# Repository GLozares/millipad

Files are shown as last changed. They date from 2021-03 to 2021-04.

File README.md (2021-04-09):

# MilliPad
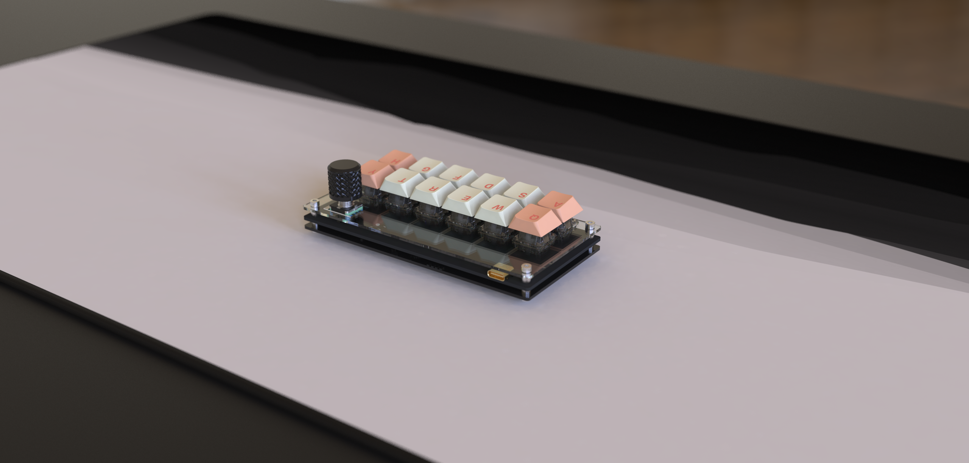
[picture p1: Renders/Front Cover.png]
Images


## A First Step into the World of Keyboards
Hi there! If you're reading this, thank you for stopping by. This is a repository detailing my first foray into custom mechanical keyboards. I decided to make a custom mechanical keypad to use for myself as my favorite keyboard layout, the 65%, does not have F1 through F12. However, in some circumstances particularly when I am coding, I would like to have those function keys. Thus, instead of buying a numpad off the shelf, I thought it was a great opportunity to make my own.

Prior to this project, I took on a group project in my Computer Engineering senior design class that involves creating our own full sized custom mechanical keyboard. I took some initiative and began to learn PCB design myself as to be a bigger asset to my group down the line.

## Credits
Apart from the dependant repositories already linked in my project, I would like to thank ai03 for their beginner's tutorial on keyboard PCB design. Their guide can be found at https://wiki.ai03.com/books/pcb-design.

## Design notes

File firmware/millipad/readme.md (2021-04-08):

# millipad

millipad

A 2x6 Macropad with Rotary Encoder. Designed to be cheap and usable.

* Keyboard Maintainer: [Jirou](https://github.com/GLozares)
* Hardware Supported: Jirou.Design Millipad
* Hardware Availability: Sag#0001

Make example for this keyboard (after setting up your build environment):

    make millipad:default

Flashing example for this keyboard:

    make millipad:default:flash

See the [build environment setup](https://docs.qmk.fm/#/getting_started_build_tools) and the [make instructions](https://docs.qmk.fm/#/getting_started_make_guide) for more information. Brand new to QMK? Start with our [Complete Newbs Guide](https://docs.qmk.fm/#/newbs).

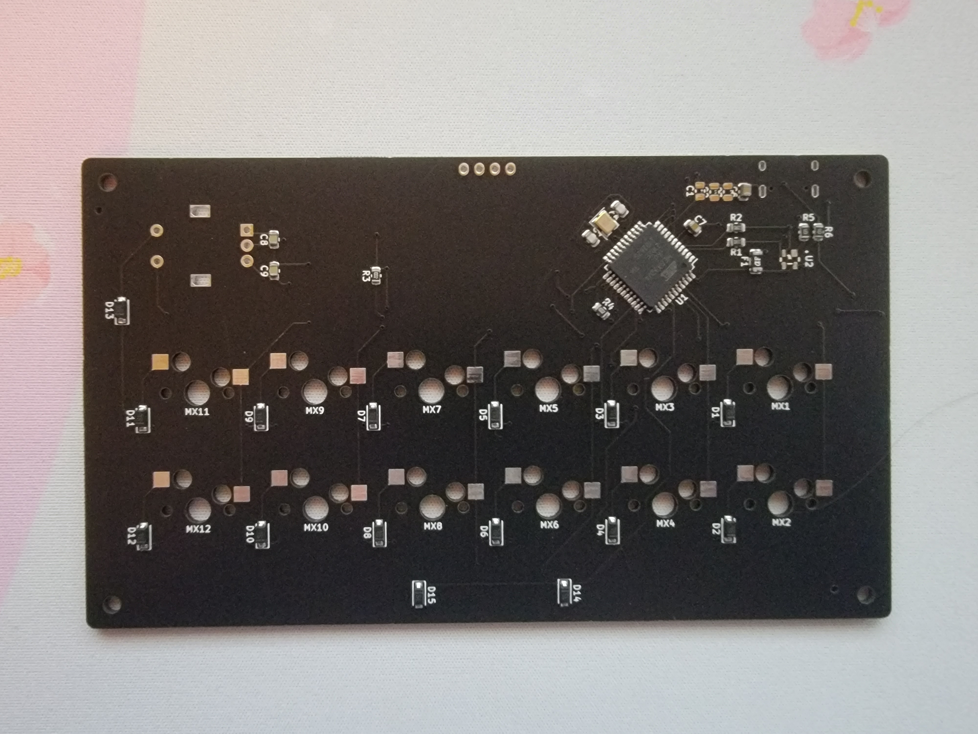
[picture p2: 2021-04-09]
miscellaneous-pictures/physical-pcb-back.jpg

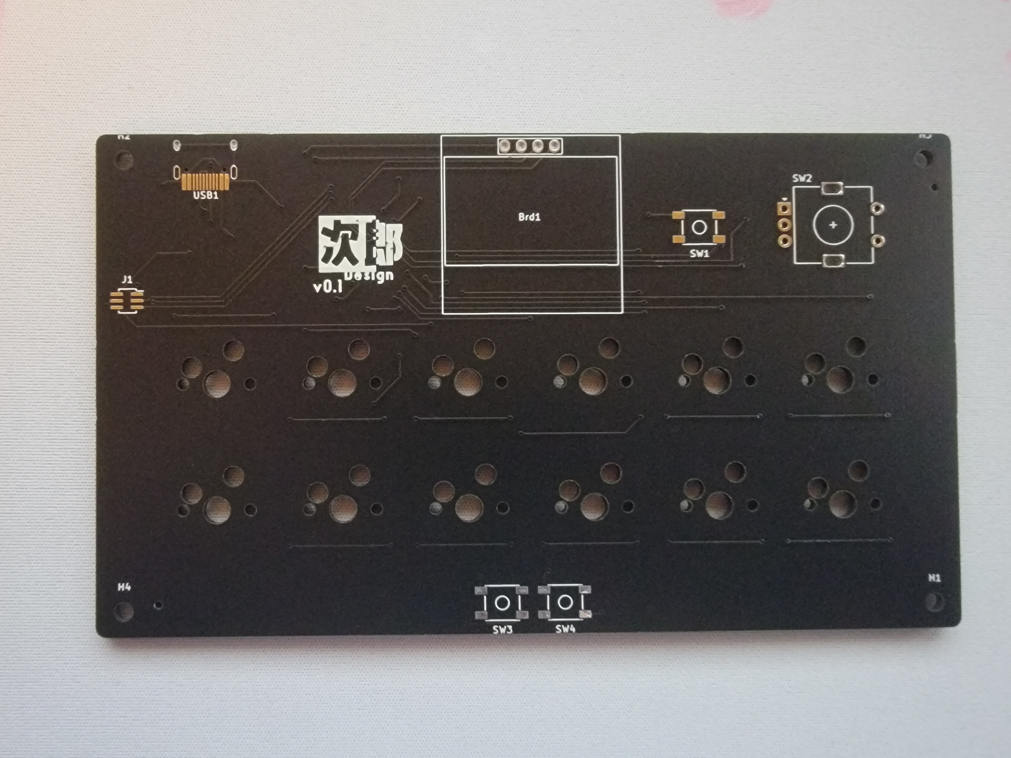
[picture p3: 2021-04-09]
miscellaneous-pictures/physical-pcb-front.jpg

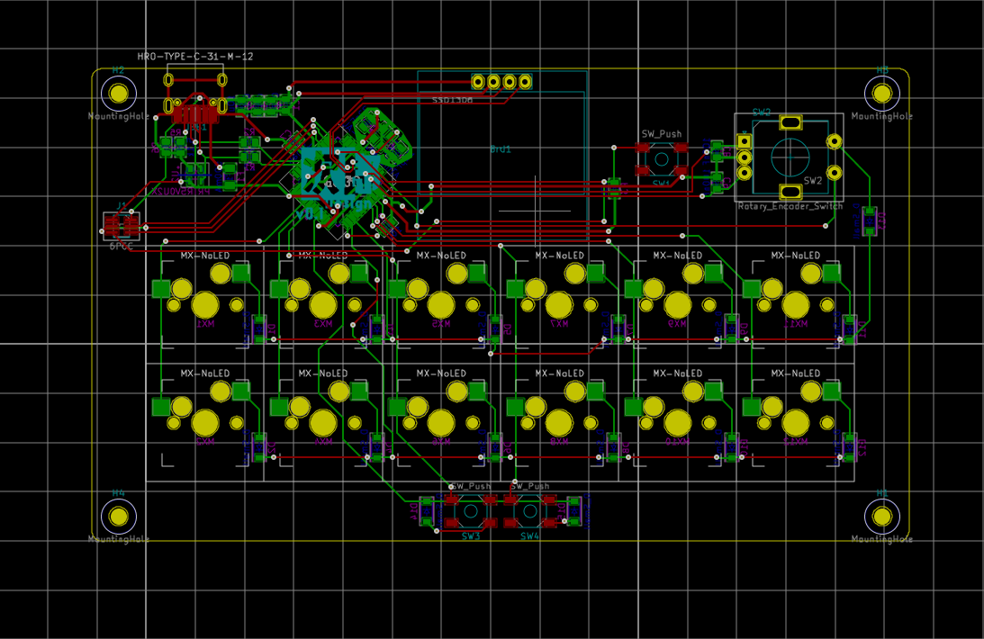
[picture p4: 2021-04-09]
miscellaneous-pictures/pcb-layout.png

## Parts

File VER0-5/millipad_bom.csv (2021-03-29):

Reference | Quantity | Value | Footprint | Datasheet
Brd1 | 1 | SSD1306 | SSD1306:128x64OLED
C1 C2 C3 | 3 | 0.1uF | Capacitor_SMD:C_0805_2012Metric | ~
C4 C5 | 2 | 22pF | Capacitor_SMD:C_0805_2012Metric | ~
C6 | 1 | 10uF | Capacitor_SMD:C_0805_2012Metric | ~
C7 | 1 | C_Small | Capacitor_SMD:C_0805_2012Metric | ~
C8 C9 | 2 | 100nF | Capacitor_SMD:C_0805_2012Metric | ~
D1 D2 D3 D4 D5 D6 D7 D8 D9 D10 D11 D12 D13 D14 D15 | 15 | D_Small | Diode_SMD:D_SOD-123 | ~
F1 | 1 | 500mA | Fuse:Fuse_1206_3216Metric | ~
H1 H2 H3 H4 | 4 | MountingHole | MountingHole:MountingHole_2.7mm_M2.5 | ~
J1 | 1 | 6P6C | Connector_PinSocket_1.00mm:PinSocket_2x03_P1.00mm_Vertical_SMD | ~
MX1 MX2 MX3 MX4 MX5 MX6 MX7 MX8 MX9 MX10 MX11 MX12 | 12 | MX-NoLED | MX_Only:MXOnly-1U-Hotswap
R1 R2 | 2 | 22 | Resistor_SMD:R_0805_2012Metric | ~
R3 R4 | 2 | 10k | Resistor_SMD:R_0805_2012Metric | ~
R5 R6 | 2 | 5.1k | Resistor_SMD:R_0805_2012Metric | ~
SW1 SW3 SW4 | 3 | SW_Push | random-keyboard-parts:SKQG-1155865 | ~
SW2 | 1 | Rotary_Encoder_Switch | Keebio-Parts:RotaryEncoder_Alps_EC11E-Switch_Vertical_H20mm | ~
U1 | 1 | ATmega32U4-AU | Package_QFP:TQFP-44_10x10mm_P0.8mm | http://ww1.microchip.com/downloads/en/DeviceDoc/Atmel-7766-8-bit-AVR-ATmega16U4-32U4_Datasheet.pdf
U2 | 1 | PRTR5V0U2X | prtr5v:PRTR5V0U2X
USB1 | 1 | HRO-TYPE-C-31-M-12 | Type-C:HRO-TYPE-C-31-M-12-HandSoldering
Y1 | 1 | 16MHz | Crystal:Crystal_SMD_3225-4Pin_3.2x2.5mm | ~

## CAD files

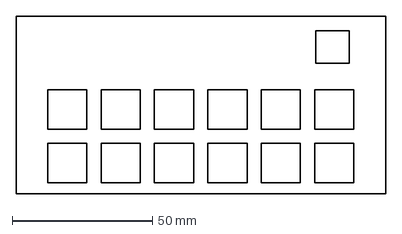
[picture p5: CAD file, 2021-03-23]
Plate/mx and encoder cutout.dxf
131.7 x 63.5 mm

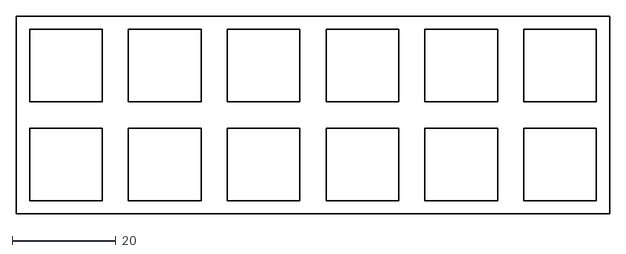
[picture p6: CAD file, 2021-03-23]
Plate/macropad plate.dxf
114.3 x 38.1

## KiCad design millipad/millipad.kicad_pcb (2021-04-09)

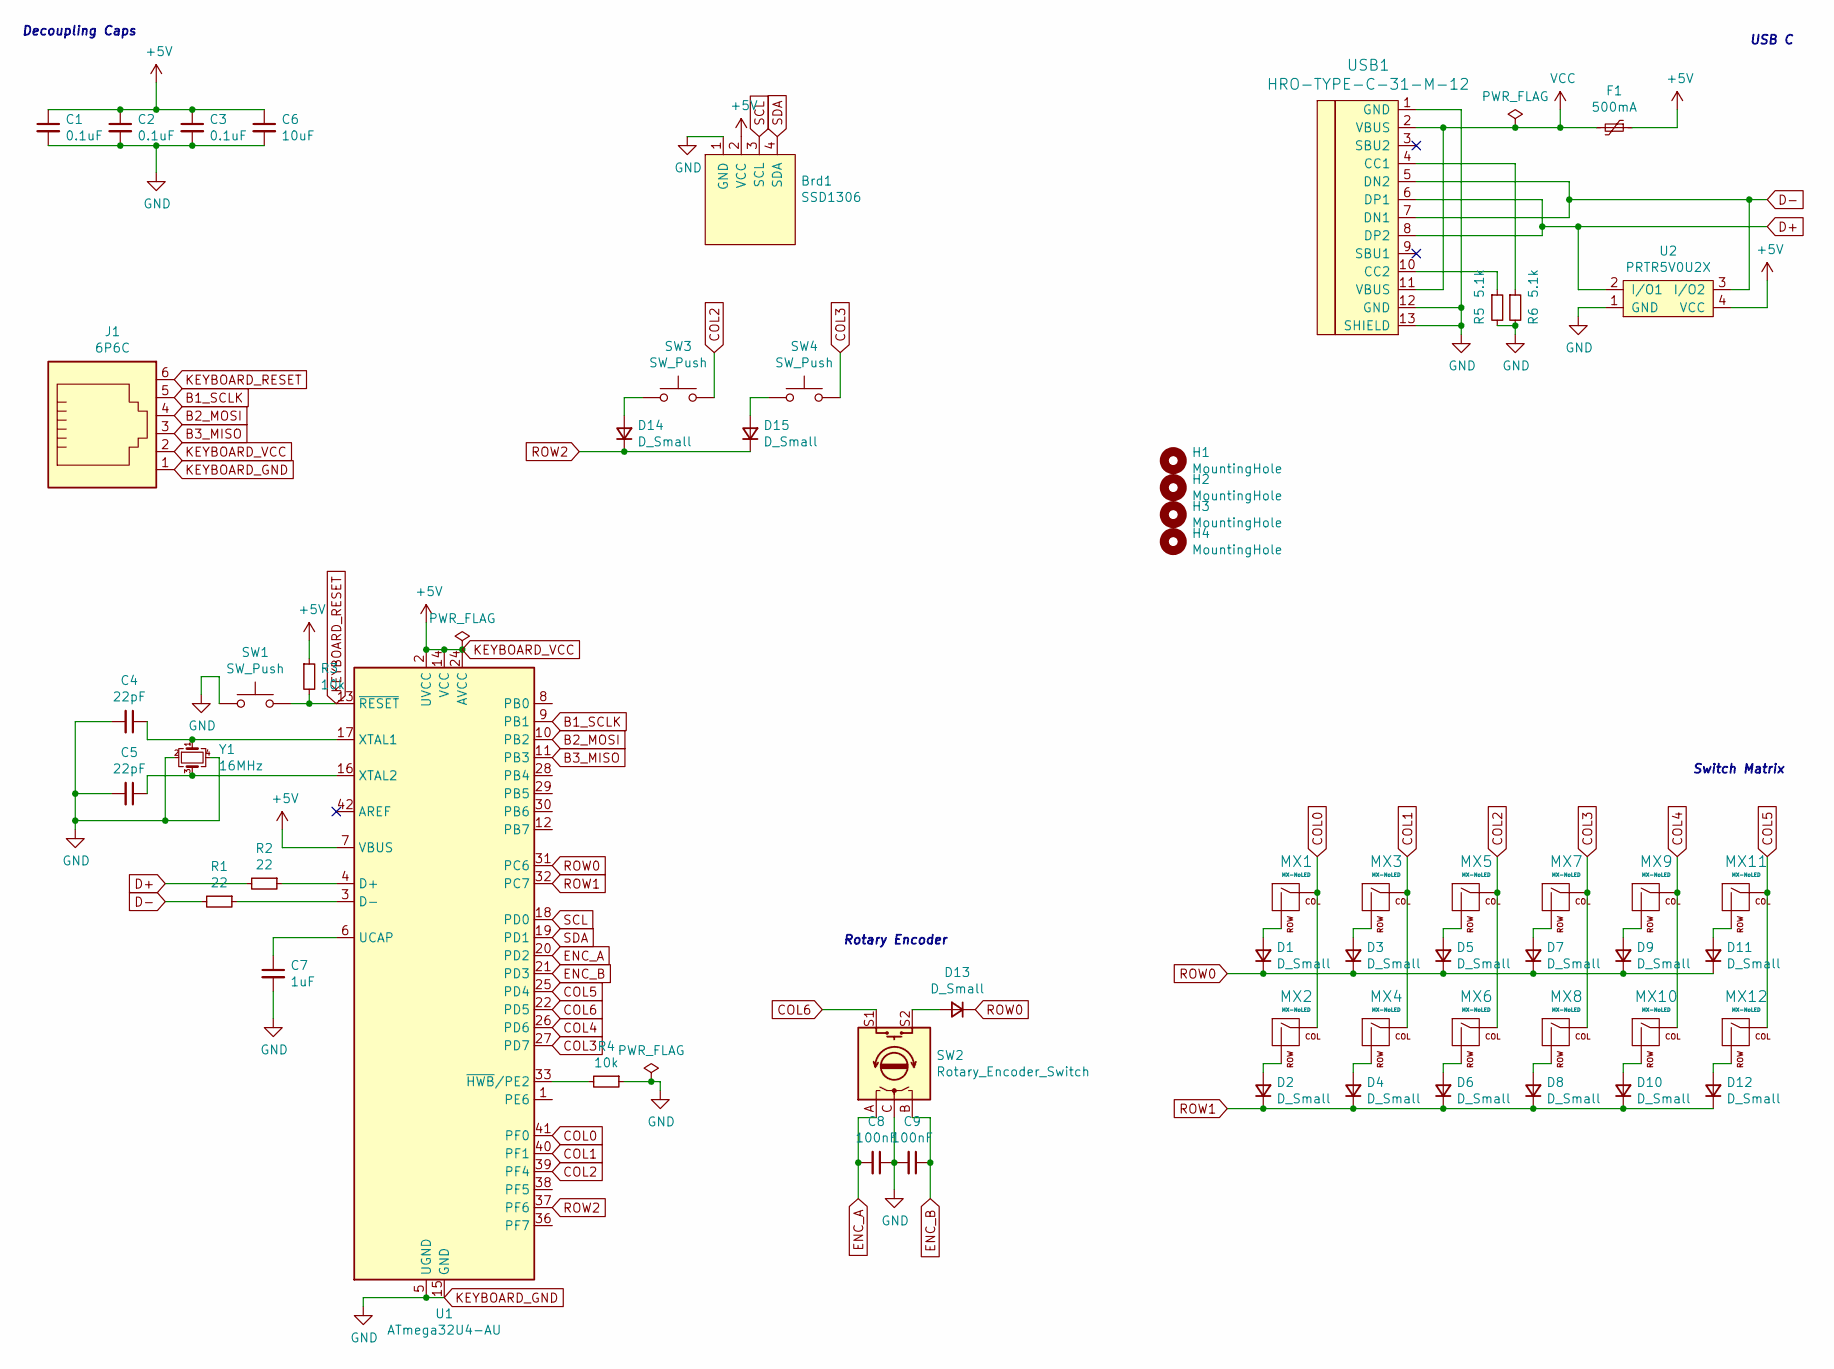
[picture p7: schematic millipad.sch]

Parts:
Brd1: SSD1306; 128x64OLED
C1, C2, C3: 0.1uF; C_0805_2012Metric
C4, C5: 22pF; C_0805_2012Metric
C6: 10uF; C_0805_2012Metric
C7: 1uF; C_0805_2012Metric
C8, C9: 100nF; C_0805_2012Metric
D1, D2, D3, D4, D5, D6, D7, D8, D9, D10, D11, D12, D13, D14, D15: D_Small; D_SOD-123
F1: 500mA; Fuse_1206_3216Metric
H1, H2, H3, H4: MountingHole; MountingHole_2.7mm_M2.5
J1: 6P6C; PinSocket_2x03_P1.00mm_Vertical_SMD
MX1, MX2, MX3, MX4, MX5, MX6, MX7, MX8, MX9, MX10, MX11, MX12: MX-NoLED; MXOnly-1U-Hotswap
R1, R2: 22; R_0805_2012Metric
R3, R4: 10k; R_0805_2012Metric
R5, R6: 5.1k; R_0805_2012Metric
SW1, SW3, SW4: SW_Push; SKQG-1155865
SW2: Rotary_Encoder_Switch; RotaryEncoder_Alps_EC11E-Switch_Vertical_H20mm
U1: ATmega32U4-AU; TQFP-44_10x10mm_P0.8mm
U2: PRTR5V0U2X
USB1: HRO-TYPE-C-31-M-12; HRO-TYPE-C-31-M-12-HandSoldering
Y1: 16MHz; Crystal_SMD_3225-4Pin_3.2x2.5mm

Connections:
B1_SCLK: J1.5, U1.9 (PB1)
B2_MOSI: J1.4, U1.10 (PB2)
B3_MISO: J1.3, U1.11 (PB3)
COL0: MX1.1 (COL), MX2.1 (COL), U1.41 (PF0)
COL1: MX3.1 (COL), MX4.1 (COL), U1.40 (PF1)
COL2: MX5.1 (COL), MX6.1 (COL), SW3.2, U1.39 (PF4)
COL3: MX7.1 (COL), MX8.1 (COL), SW4.2, U1.27 (PD7)
COL4: MX9.1 (COL), MX10.1 (COL), U1.26 (PD6)
COL5: MX11.1 (COL), MX12.1 (COL), U1.25 (PD4)
COL6: SW2.S1, U1.22 (PD5)
D+: R2.2, U2.2 (I/O1), USB1.6 (DP1), USB1.8 (DP2)
D-: R1.2, U2.3 (I/O2), USB1.5 (DN2), USB1.7 (DN1)
ENC_A: C8.2, SW2.A, U1.20 (PD2)
ENC_B: C9.1, SW2.B, U1.21 (PD3)
KEYBOARD_GND: Brd1.1 (GND), C1.2, C2.2, C3.2, C4.2, C5.2, C6.2, C7.2, C8.1, C9.2, J1.1, R4.1, R5.2, R6.2, SW1.1, SW2.C, U1.5 (UGND), U1.15 (GND), U1.23 (GND), U1.35 (GND), U1.43 (GND), U2.1 (GND), USB1.1 (GND), USB1.12 (GND), USB1.13 (SHIELD), Y1.2, Y1.4
KEYBOARD_RESET: J1.6, R3.2, SW1.2, U1.13 (~RESET)
KEYBOARD_VCC: Brd1.2 (VCC), C1.1, C2.1, C3.1, C6.1, F1.1, J1.2, R3.1, U1.2 (UVCC), U1.7 (VBUS), U1.14 (VCC), U1.24 (AVCC), U1.34 (VCC), U1.44 (AVCC), U2.4 (VCC)
unnamed: C4.1, U1.17 (XTAL1), Y1.1
unnamed: C5.1, U1.16 (XTAL2), Y1.3
unnamed: C7.1, U1.6 (UCAP)
unnamed: D1.2 (A), MX1.2 (ROW)
unnamed: D2.2 (A), MX2.2 (ROW)
unnamed: D3.2 (A), MX3.2 (ROW)
unnamed: D4.2 (A), MX4.2 (ROW)
unnamed: D5.2 (A), MX5.2 (ROW)
unnamed: D6.2 (A), MX6.2 (ROW)
unnamed: D7.2 (A), MX7.2 (ROW)
unnamed: D8.2 (A), MX8.2 (ROW)
unnamed: D9.2 (A), MX9.2 (ROW)
unnamed: D10.2 (A), MX10.2 (ROW)
unnamed: D11.2 (A), MX11.2 (ROW)
unnamed: D12.2 (A), MX12.2 (ROW)
unnamed: D13.2 (A), SW2.S2
unnamed: D14.2 (A), SW3.1
unnamed: D15.2 (A), SW4.1
unnamed: R1.1, U1.3 (D-)
unnamed: R2.1, U1.4 (D+)
unnamed: R4.2, U1.33 (~HWB~/PE2)
unnamed: R5.1, USB1.10 (CC2)
unnamed: R6.1, USB1.4 (CC1)
ROW0: D1.1 (K), D3.1 (K), D5.1 (K), D7.1 (K), D9.1 (K), D11.1 (K), D13.1 (K), U1.31 (PC6)
ROW1: D2.1 (K), D4.1 (K), D6.1 (K), D8.1 (K), D10.1 (K), D12.1 (K), U1.32 (PC7)
ROW2: D14.1 (K), D15.1 (K), U1.37 (PF6)
SCL: Brd1.3 (SCL), U1.18 (PD0)
SDA: Brd1.4 (SDA), U1.19 (PD1)
VCC: F1.2, USB1.2 (VBUS), USB1.11 (VBUS)

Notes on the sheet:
Decoupling Caps
USB C
Switch Matrix
Rotary Encoder

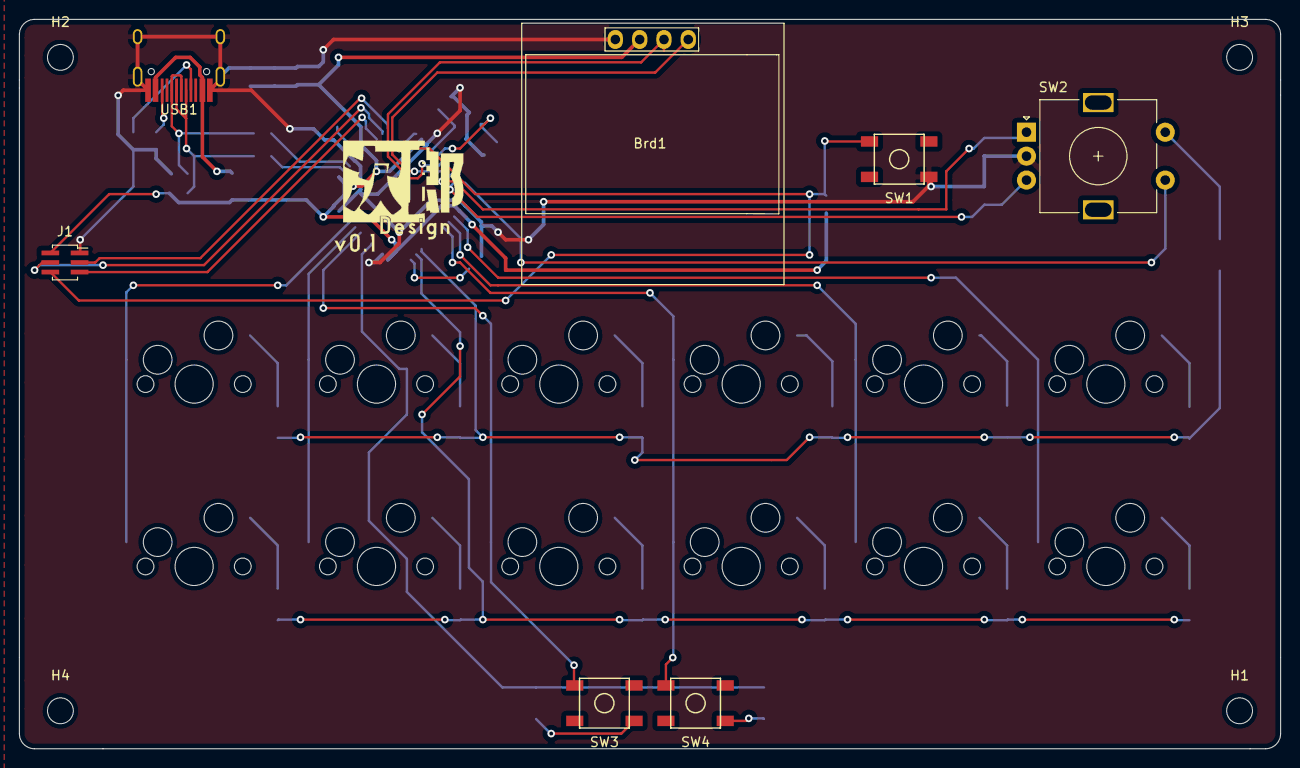
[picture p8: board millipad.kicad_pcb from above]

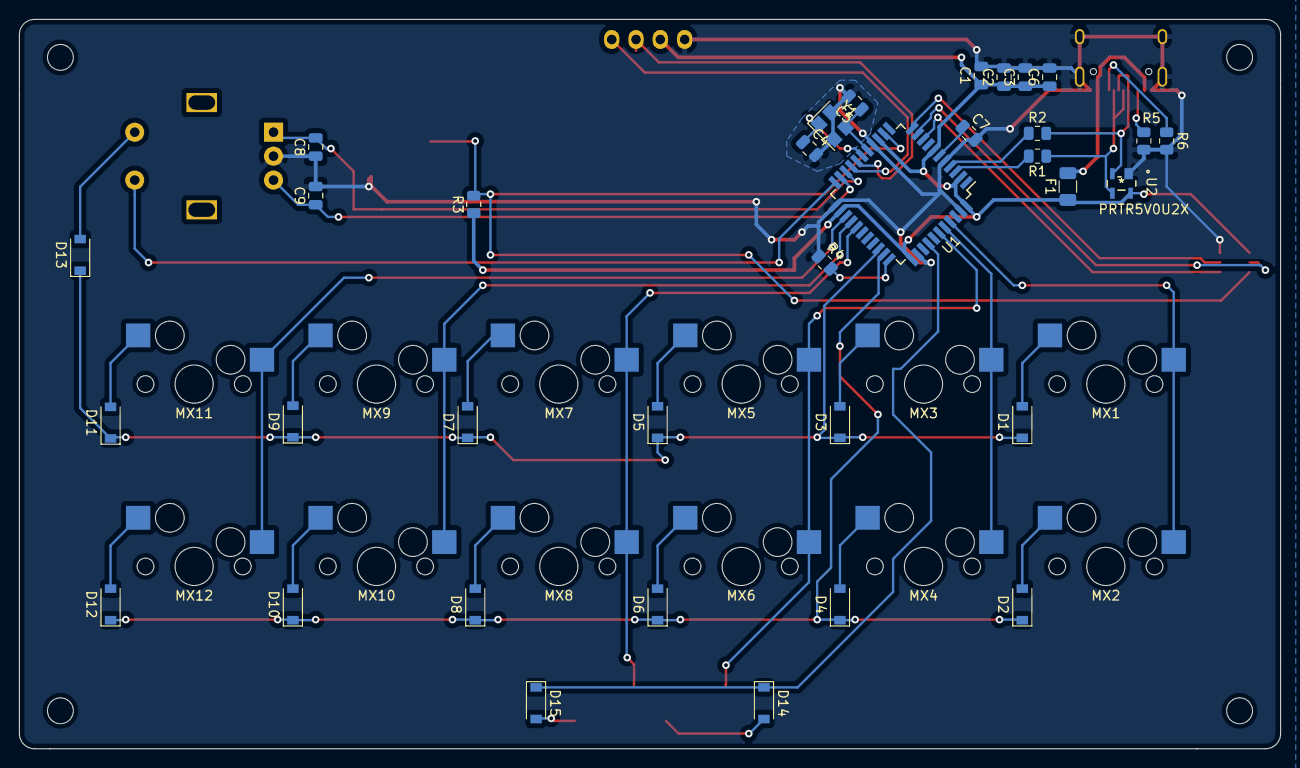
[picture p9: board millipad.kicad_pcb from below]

Board: 2 copper layers, 131.8 x 76.2 mm, 57 parts (34 on the bottom side), 46 nets.

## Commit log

2021-03-22 Added dependencies
    [millipad.kicad_pcb, millipad.sch]
2021-03-22 MCU Schematic
2021-03-22 PCB Layout
    [millipad.sch]
2021-03-23 3d work
    [macropad plate.dxf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]
2021-03-28 Rewired CPU to fit OLED
    [millipad.kicad_pcb]
2021-03-28 Added SSD1306 128x64 OLED Breakout Board
    [millipad.kicad_pcb, millipad.sch]
2021-03-28 Added pushbutton and isp flash headers
    [millipad.kicad_pcb, millipad.sch]
2021-03-29 Generated BOM, POS, STEP for Plate Assembly
    [millipad-B_Cu.gbr, millipad-B_Mask.gbr, millipad-B_Paste.gbr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]
2021-04-05 Created manufacturing files for production and uploaded renders
    [millipad-B_Cu.gbr, millipad-B_Mask.gbr, millipad-B_Paste.gbr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]
2021-04-09 ground planes
    [millipad.kicad_pcb]

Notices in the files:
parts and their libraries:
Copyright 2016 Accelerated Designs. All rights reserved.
